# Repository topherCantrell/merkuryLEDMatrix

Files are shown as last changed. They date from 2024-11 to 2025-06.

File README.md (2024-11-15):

# Merkury Innovations Bluetooth Matrix LED Display

https://www.walmart.com/ip/Merkury-Innovations-Bluetooth-Matrix-LED-Pixel-Display/5150283693

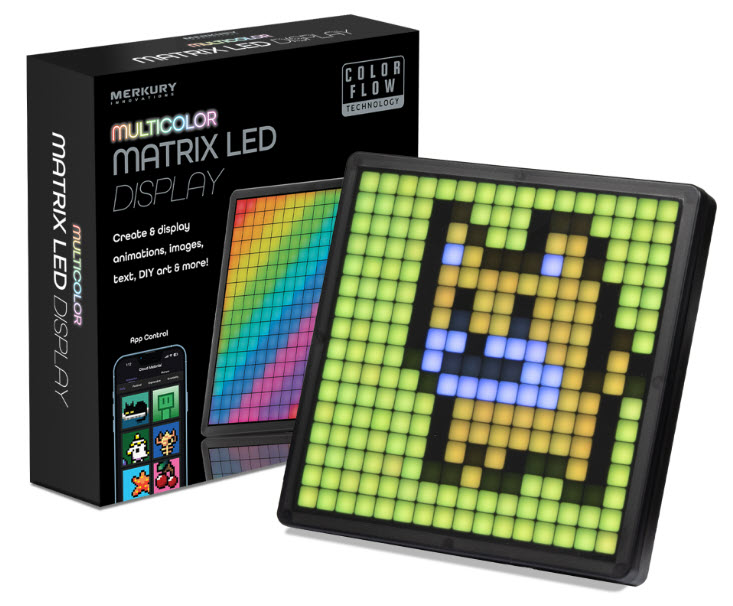
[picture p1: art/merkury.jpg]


The LEDs are a single strand of 256 neopixels. The circuit board has a single IC that handles
bluetooth and drives the LEDs.

I used a continuity checker to trace the first neopixel to pin 9 of the IC (U1).

I used a soldering iron to carefully lift pin 9 from the circuit board. I attached a blue wire to the
circuit board pad. This drives the neopixels. I attached a green wire to the lifted pin 9.

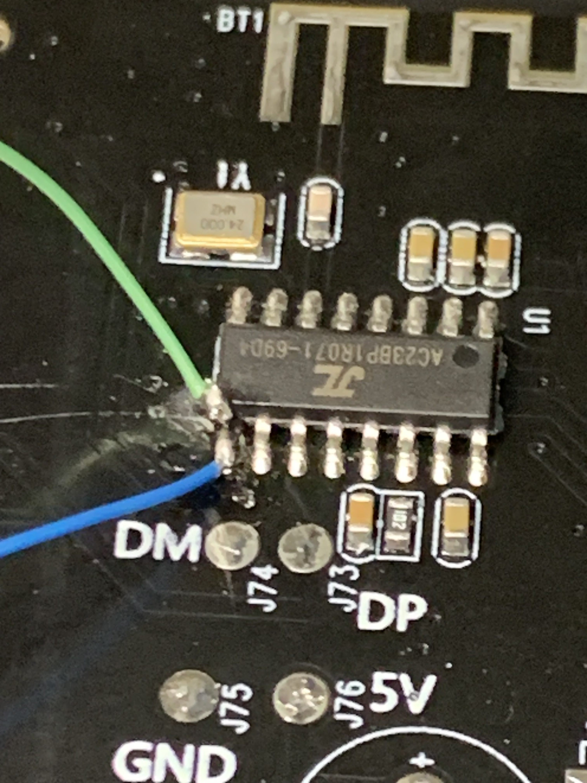
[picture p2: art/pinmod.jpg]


I added a SPDT switch to select the neopixel input: original or my raspberry pi pico.

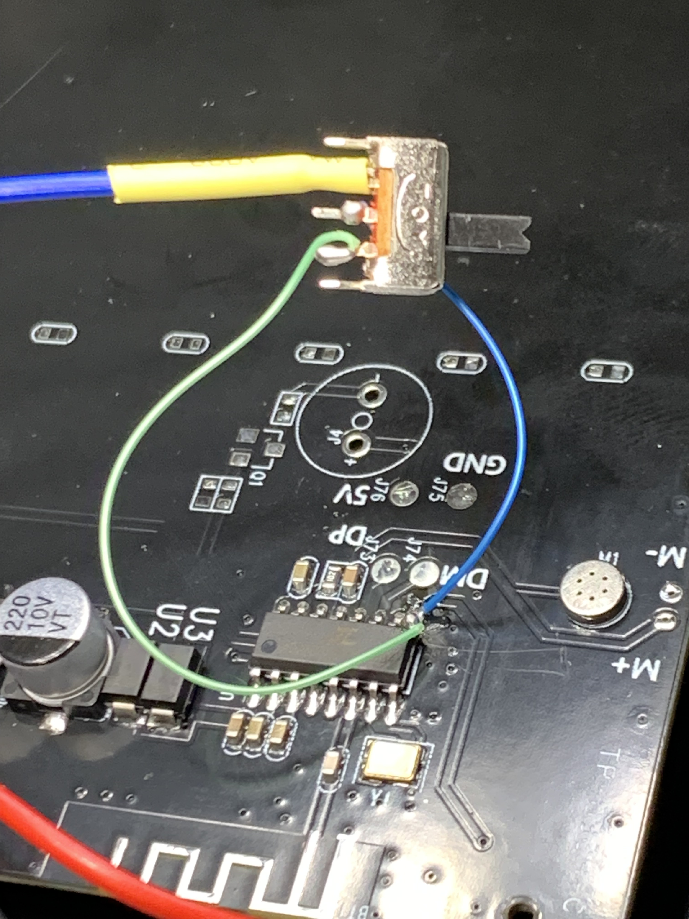
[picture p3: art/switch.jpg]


I removed the existing USB power cable. I'll use a full USB cable that carries data (for programming) and
power. I wired the pico VBUS and GND to the circuit board where the old USB cable was attached.

The pico GP0 pin drives the neopixels. The pico is a 3.3V part, but the neopixels on my board recognizes the 
logic levels correctly. If your panel does not, you can add a level shifter such as: 
[DEVMO-Converter-Bi-Directional-Module-Arduino/dp/B07SZQMWFS](https://www.amazon.com/DEVMO-Converter-Bi-Directional-Module-Arduino/dp/B07SZQMWFS)

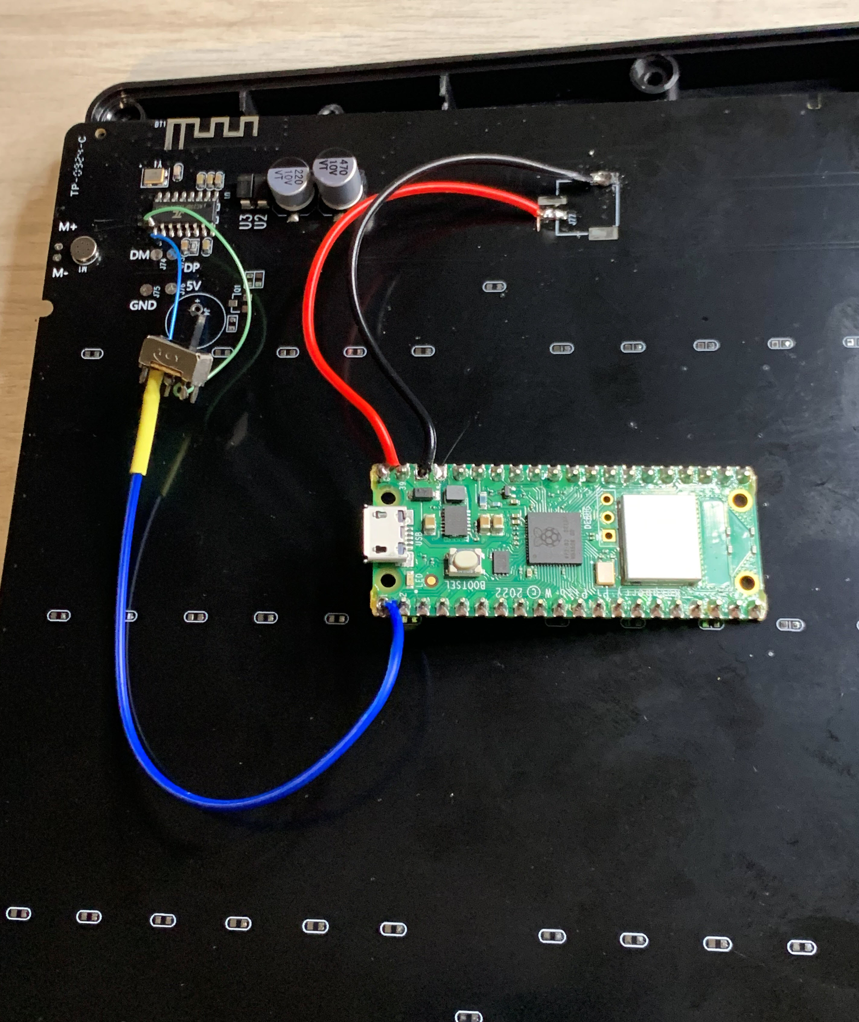
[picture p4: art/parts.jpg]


I used a drop of superglue to mount the switch to the circuit board. Packing tape secures the pico to keep it
from sliding around.

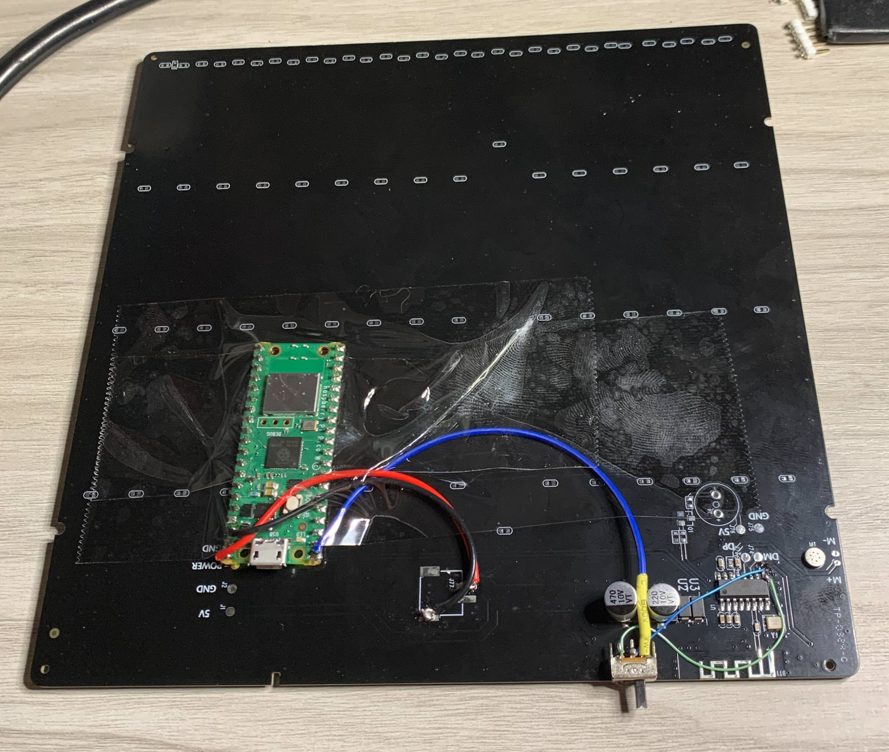
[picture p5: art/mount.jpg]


I drilled a hole in the side of the case for access to the switch. I had to widen the existing USB cable hole
to push my new cable through. I plugged the USB into the pico, made sure everything was working, and 
reassembled the case.

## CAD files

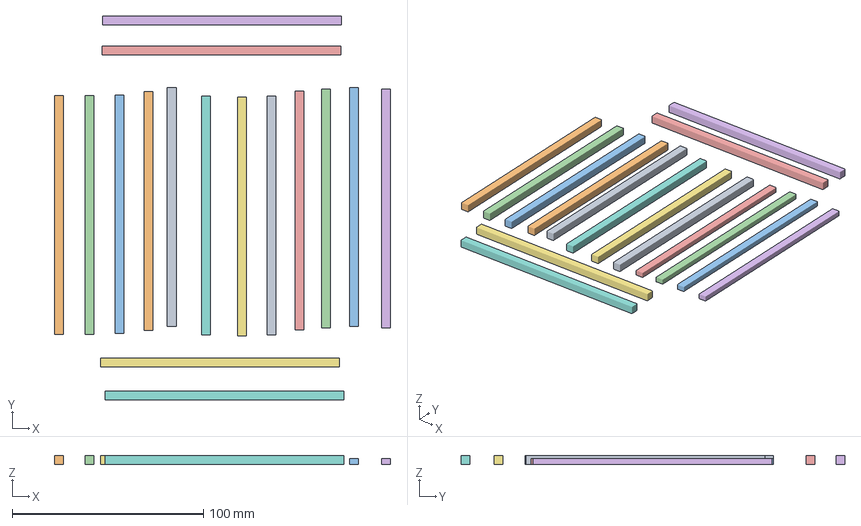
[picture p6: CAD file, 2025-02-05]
MerkSticks.3mf
175.9 x 200.9 x 4.50 mm

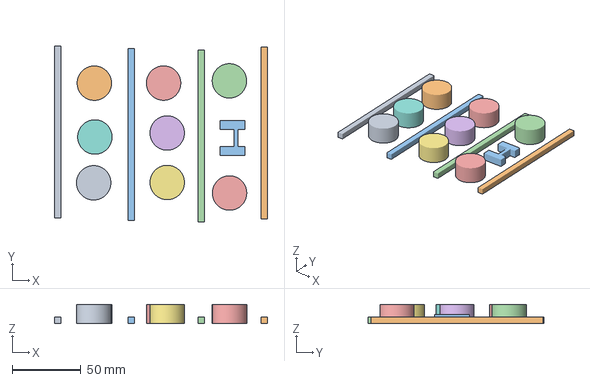
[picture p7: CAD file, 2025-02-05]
Merkury.3mf
154.7 x 127.8 x 14.0 mm

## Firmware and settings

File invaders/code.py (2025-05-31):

import neopixel
import board
import time
import random
# import busio
# import adafruit_nunchuk

# i2c = busio.I2C(board.GP13, board.GP12)
# nc = adafruit_nunchuk.Nunchuk(i2c)

pixels = neopixel.NeoPixel(board.GP6, 256, auto_write=False)

pixels.fill((0, 0, 0))
pixels.show()

# import wifi
# wifi.radio.start_ap('TopMat','TopMatPass')

pal = [
    (0, 0, 0),
    (0, 50, 0),
    (0, 0, 50),
    (10, 50, 10),
    (50, 50, 50),
]

inv1 = [
    0, 0, 0, 0, 0, 0, 0, 0, 0, 0, 0, 0, 0, 0, 0, 0,
    0, 0, 0, 0, 0, 0, 0, 0, 0, 0, 0, 0, 0, 0, 0, 0,
    0, 0, 0, 0, 0, 0, 0, 0, 0, 0, 0, 0, 0, 0, 0, 0,
    0, 0, 0, 0, 0, 0, 0, 0, 0, 0, 0, 0, 0, 0, 0, 0,
    0, 0, 0, 0, 0, 0, 3, 3, 3, 3, 0, 0, 0, 0, 0, 0,
    0, 0, 0, 3, 3, 3, 3, 3, 3, 3, 3, 3, 3, 0, 0, 0,
    0, 0, 3, 3, 3, 3, 3, 3, 3, 3, 3, 3, 3, 3, 0, 0,
    0, 0, 3, 3, 3, 4, 4, 3, 3, 4, 4, 3, 3, 3, 0, 0,
    0, 0, 3, 3, 3, 3, 3, 3, 3, 3, 3, 3, 3, 3, 0, 0,
    0, 0, 0, 0, 0, 3, 3, 0, 0, 3, 3, 0, 0, 0, 0, 0,
    0, 0, 0, 0, 3, 3, 0, 3, 3, 0, 3, 3, 0, 0, 0, 0,
    0, 0, 3, 3, 0, 0, 0, 0, 0, 0, 0, 0, 3, 3, 0, 0,
    0, 0, 0, 0, 0, 0, 0, 0, 0, 0, 0, 0, 0, 0, 0, 0,
    0, 0, 0, 0, 0, 0, 0, 0, 0, 0, 0, 0, 0, 0, 0, 0,
    0, 0, 0, 0, 0, 0, 0, 0, 0, 0, 0, 0, 0, 0, 0, 0,
    0, 0, 0, 0, 0, 0, 0, 0, 0, 0, 0, 0, 0, 0, 0, 0,
]

inv2 = [
    0, 0, 0, 0, 0, 0, 0, 0, 0, 0, 0, 0, 0, 0, 0, 0,
    0, 0, 0, 0, 0, 0, 0, 0, 0, 0, 0, 0, 0, 0, 0, 0,
    0, 0, 0, 0, 0, 0, 0, 0, 0, 0, 0, 0, 0, 0, 0, 0,
    0, 0, 0, 0, 0, 0, 0, 0, 0, 0, 0, 0, 0, 0, 0, 0,
    0, 0, 0, 0, 0, 0, 3, 3, 3, 3, 0, 0, 0, 0, 0, 0,
    0, 0, 0, 3, 3, 3, 3, 3, 3, 3, 3, 3, 3, 0, 0, 0,
    0, 0, 3, 3, 3, 3, 3, 3, 3, 3, 3, 3, 3, 3, 0, 0,
    0, 0, 3, 3, 3, 4, 4, 3, 3, 4, 4, 3, 3, 3, 0, 0,
    0, 0, 3, 3, 3, 3, 3, 3, 3, 3, 3, 3, 3, 3, 0, 0,
    0, 0, 0, 0, 3, 3, 3, 0, 0, 3, 3, 3, 0, 0, 0, 0,
    0, 0, 0, 3, 3, 0, 0, 3, 3, 0, 0, 3, 3, 0, 0, 0,
    0, 0, 0, 0, 3, 3, 0, 0, 0, 0, 3, 3, 0, 0, 0, 0,
    0, 0, 0, 0, 0, 0, 0, 0, 0, 0, 0, 0, 0, 0, 0, 0,
    0, 0, 0, 0, 0, 0, 0, 0, 0, 0, 0, 0, 0, 0, 0, 0,
    0, 0, 0, 0, 0, 0, 0, 0, 0, 0, 0, 0, 0, 0, 0, 0,
    0, 0, 0, 0, 0, 0, 0, 0, 0, 0, 0, 0, 0, 0, 0, 0,
]

invaders = [inv1, inv2]

def draw_frame(pal, data):
    for i in range(256):
        pixels[i] = pal[data[i]]
    pixels.show()


def four_by_four_trans(dest, data, x, y):
    for yy in range(16):
        ay = yy+y
        if ay < 0 or ay > 15:
            # Not visible
            continue
        for xx in range(16):
            ax = xx + x
            if ax < 0 or ax > 15:
                # Not visible
                continue
            d = data[yy*16+xx]
            if d:
                # Not transparent
                dest[ay*16 + ax] = d


MIN_X = -4
MIN_Y = -4
MAX_X = 4
MAX_Y = 4

x = 0
y = 0
inv = 0
dx = 1
dy = 1
while True:
    can = [0]*256
    four_by_four_trans(can, invaders[inv], x, y)
    # print(x, y, dx, dy, nc.joystick)
    draw_frame(pal, can)
    time.sleep(0.25)

    # Flip animation
    inv += 1
    inv = inv % 2

    if nc.buttons.Z:
        x,y = nc.joystick
        x = int(x / 16) - 8
        y = 16 - int(y / 16) - 8
        continue

    if x < MIN_X or x > MAX_X or y < MIN_Y or y > MAX_Y:
        # Time to change direction
        if x <= MIN_X:
            x = MIN_X
            while True:
                dx = random.choice([0, 1, 2])
                # dy = random.choice([-2, -1, 0, 1, 2])
                if dx or dy:
                    break
        if x >= MAX_X:
            x = MAX_X
            while True:
                dx = random.choice([0, -1, -2])
                # dy = random.choice([-2, -1, 0, 1, 2])
                if dx or dy:
                    break
        if y <= MIN_Y:
            y = MIN_Y
            while True:
                dy = random.choice([0, 1, 2])
                # dx = random.choice([-2, -1, 0, 1, 2])
                if dx or dy:
                    break
        if y >= MAX_Y:
            y = MAX_Y
            while True:
                dy = random.choice([0, -1, -2])
                # dx = random.choice([-2, -1, 0, 1, 2])
                if dx or dy:
                    break

    x = x + dx
    y = y + dy

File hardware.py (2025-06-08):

import neopixel
import board
import busio
import adafruit_nunchuk
import adafruit_mpu6050 


class MerkuryHardware:

    def __init__(self, use_nunchuk=True):

        # Strand of 256 neopixels on pin GP6
        self._neo_pixels = neopixel.NeoPixel(board.GP6, 256, auto_write=False)
        self._neo_pixels.fill((0, 0, 0))
        self._neo_pixels.show()

        # MPU6050 accelerometer on an I2C bus 1: GP15 and GP14
        self._acc_i2c = busio.I2C(board.GP15, board.GP14)
        self._mpu = adafruit_mpu6050.MPU6050(self._acc_i2c)

        # Not every panel has a nunchuk
        if use_nunchuk:
            # Nunchuk on I2C bus 0: GP1 and GP0
            # It might be plugged in later, so we don't create it yet
            self._nc_i2c = busio.I2C(board.GP1, board.GP0)
            self._nunchuk = None       

    def get_neo_pixels(self):
        """return the neopixels object

        You can do things like:
        ret.fill((0, 0, 10))
        ret.show()
        ret[0] = (10, 10, 10)        
        """        
        return self._neo_pixels
    
    def get_accelerometer(self):        
        """return the accelerometer object
        You can do things like:
        
        ret.acceleration
        """       
        return self._mpu
    
    def get_nunchuk(self):
        """return the nunchuk object
        You can do things like:
        ret.joystick
        ret.joystick.x
        ret.joystick.y
        ret.buttons
        """
        if self._nunchuk is None:
            try:
                self._nunchuk = adafruit_nunchuk.Nunchuk(self._nc_i2c)
            except Exception:
                print("Nunchuk not found")
                self._nunchuk = None                
        return self._nunchuk
    
